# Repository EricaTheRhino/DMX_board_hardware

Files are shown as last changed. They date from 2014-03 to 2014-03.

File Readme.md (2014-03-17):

Hardware designs for Erica led controller
=========================================

Designs where made in eagle 6.4

Jumper options
--------------

SJ1/SJ2 used for DMX passthough if not populating second rs485 converter (U3)
SJ3 used for linking logic and led power systems together for use with a single power supply
SJ4 links return serial from TLC5940 to avr if wanted

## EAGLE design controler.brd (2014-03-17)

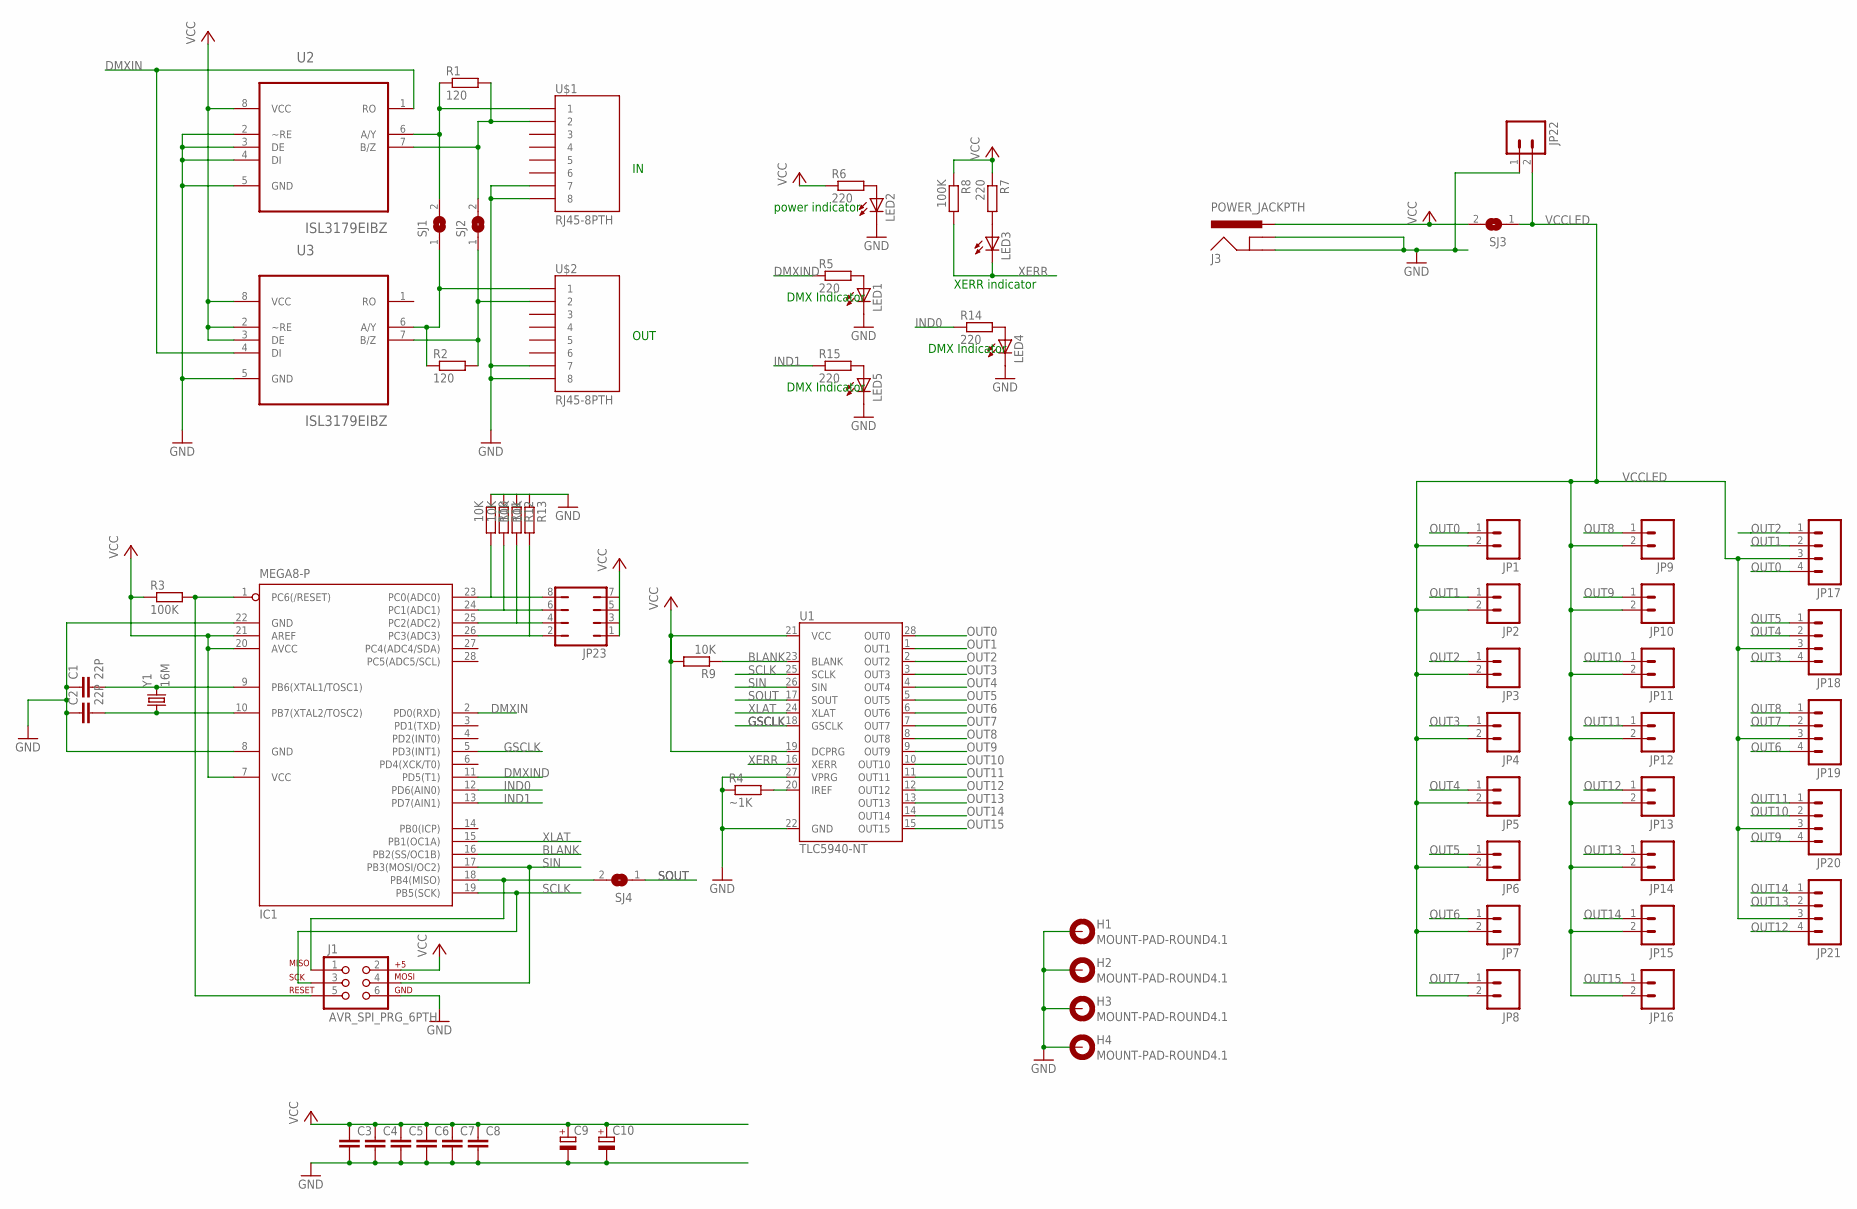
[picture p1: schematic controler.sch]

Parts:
C1, C2: 22P; C0603
C3, C4, C5, C6, C7, C8: C-EUC0603; C0603
C9: CPOL-EUE2.5-6; E2,5-6
C10: CPOL-EUE3.5-10; E3,5-10
H1, H2, H3, H4: MOUNT-PAD-ROUND4.1; 4,1-PAD
IC1: MEGA8-P; DIL28-3
J1: AVR_SPI_PRG_6PTH; 2X3
J3: POWER_JACKPTH; POWER_JACK_PTH
JP1, JP2, JP3, JP4, JP5, JP6, JP7, JP8, JP9, JP10, JP11, JP12, JP13, JP14, JP15, JP16: M02POLAR; MOLEX-1X2
JP17, JP18, JP19, JP20, JP21: M04POLAR; MOLEX-1X4
JP22: M023.5MM; SCREWTERMINAL-3.5MM-2
JP23: JP4Q
LED1, LED2, LED3, LED4, LED5: LEDCHIPLED_0603; CHIPLED_0603
R1, R2: 120; R0603
R3, R8: 100K; R0603
R4: ~1K; R0603
R5, R6, R7, R14, R15: 220; R0603
R9, R10, R11, R12, R13: 10K; R0603
SJ1, SJ2, SJ4: SJ
SJ3: SJW
U1: TLC5940-NT; DIL28-3
U2, U3: ISL3179EIBZ; SOIC127P600X175-8N
U$1, U$2: RJ45-8PTH; RJ45-8
Y1: 16M; HC49US

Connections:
BLANK: IC1.16 (PB2(SS/OC1B)), R9.1, U1.23 (BLANK)
DMXIN: IC1.2 (PD0(RXD)), U2.1 (RO), U3.4 (DI)
DMXIND: IC1.11 (PD5(T1)), R5.1
GND: C1.1, C2.1, C3.2, C4.2, C5.2, C6.2, C7.2, C8.2, C9.-, C10.-, H1.B4,1, H2.B4,1, H3.B4,1, H4.B4,1, IC1.8 (GND), IC1.22 (GND), J1.6, J3.GND, J3.GNDBREAK, JP22.1, LED1.C, LED2.C, LED4.C, LED5.C, R4.1, R10.1, R11.1, R12.1, R13.1, U1.22 (GND), U1.27 (VPRG), U2.2 (~RE), U2.3 (DE), U2.4 (DI), U2.5 (GND), U3.5 (GND), U$1.7, U$1.8, U$2.7, U$2.8
GSCLK: IC1.5 (PD3(INT1)), U1.18 (GSCLK)
IND0: IC1.12 (PD6(AIN0)), R14.1
IND1: IC1.13 (PD7(AIN1)), R15.1
unnamed: R1.1, SJ1.2, U2.6 (A/Y), U$1.1
unnamed: R1.2, SJ2.2, U2.7 (B/Z), U$1.2
unnamed: R2.1, SJ1.1, U3.6 (A/Y), U$2.1
unnamed: R2.2, SJ2.1, U3.7 (B/Z), U$2.2
unnamed: C1.2, IC1.9 (PB6(XTAL1/TOSC1)), Y1.2
unnamed: C2.2, IC1.10 (PB7(XTAL2/TOSC2)), Y1.1
unnamed: IC1.23 (PC0(ADC0)), JP23.8, R10.2
unnamed: IC1.24 (PC1(ADC1)), JP23.6, R11.2
unnamed: IC1.1 (PC6(/RESET)), J1.5, R3.2
unnamed: IC1.25 (PC2(ADC2)), JP23.4, R12.2
unnamed: IC1.18 (PB4(MISO)), J1.1, SJ4.2
unnamed: IC1.26 (PC3(ADC3)), JP23.2, R13.2
unnamed: LED5.A, R15.2
unnamed: R4.2, U1.20 (IREF)
unnamed: LED3.A, R7.2
unnamed: LED1.A, R5.2
unnamed: LED4.A, R14.2
unnamed: LED2.A, R6.2
OUT0: JP1.1, JP17.4, U1.28 (OUT0)
OUT1: JP2.1, JP17.2, U1.1 (OUT1)
OUT2: JP3.1, JP17.1, U1.2 (OUT2)
OUT3: JP4.1, JP18.4, U1.3 (OUT3)
OUT4: JP5.1, JP18.2, U1.4 (OUT4)
OUT5: JP6.1, JP18.1, U1.5 (OUT5)
OUT6: JP7.1, JP19.4, U1.6 (OUT6)
OUT7: JP8.1, JP19.2, U1.7 (OUT7)
OUT8: JP9.1, JP19.1, U1.8 (OUT8)
OUT9: JP10.1, JP20.4, U1.9 (OUT9)
OUT10: JP11.1, JP20.2, U1.10 (OUT10)
OUT11: JP12.1, JP20.1, U1.11 (OUT11)
OUT12: JP13.1, JP21.4, U1.12 (OUT12)
OUT13: JP14.1, JP21.2, U1.13 (OUT13)
OUT14: JP15.1, JP21.1, U1.14 (OUT14)
OUT15: JP16.1, U1.15 (OUT15)
SCLK: IC1.19 (PB5(SCK)), J1.3, U1.25 (SCLK)
SIN: IC1.17 (PB3(MOSI/OC2)), J1.4, U1.26 (SIN)
SOUT: SJ4.1, U1.17 (SOUT)
VCC: C3.1, C4.1, C5.1, C6.1, C7.1, C8.1, C9.+, C10.+, IC1.7 (VCC), IC1.20 (AVCC), IC1.21 (AREF), J1.2, J3.PWR, JP23.1, JP23.3, JP23.5, JP23.7, R3.1, R6.1, R7.1, R8.1, R9.2, SJ3.2, U1.19 (DCPRG), U1.21 (VCC), U2.8 (VCC), U3.2 (~RE), U3.3 (DE), U3.8 (VCC)
VCCLED: JP1.2, JP2.2, JP3.2, JP4.2, JP5.2, JP6.2, JP7.2, JP8.2, JP9.2, JP10.2, JP11.2, JP12.2, JP13.2, JP14.2, JP15.2, JP16.2, JP17.3, JP18.3, JP19.3, JP20.3, JP21.3, JP22.2, SJ3.1
XERR: LED3.C, R8.2, U1.16 (XERR)
XLAT: IC1.15 (PB1(OC1A)), U1.24 (XLAT)

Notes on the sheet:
OUT
DMX Indicator
power indicator
XERR indicator

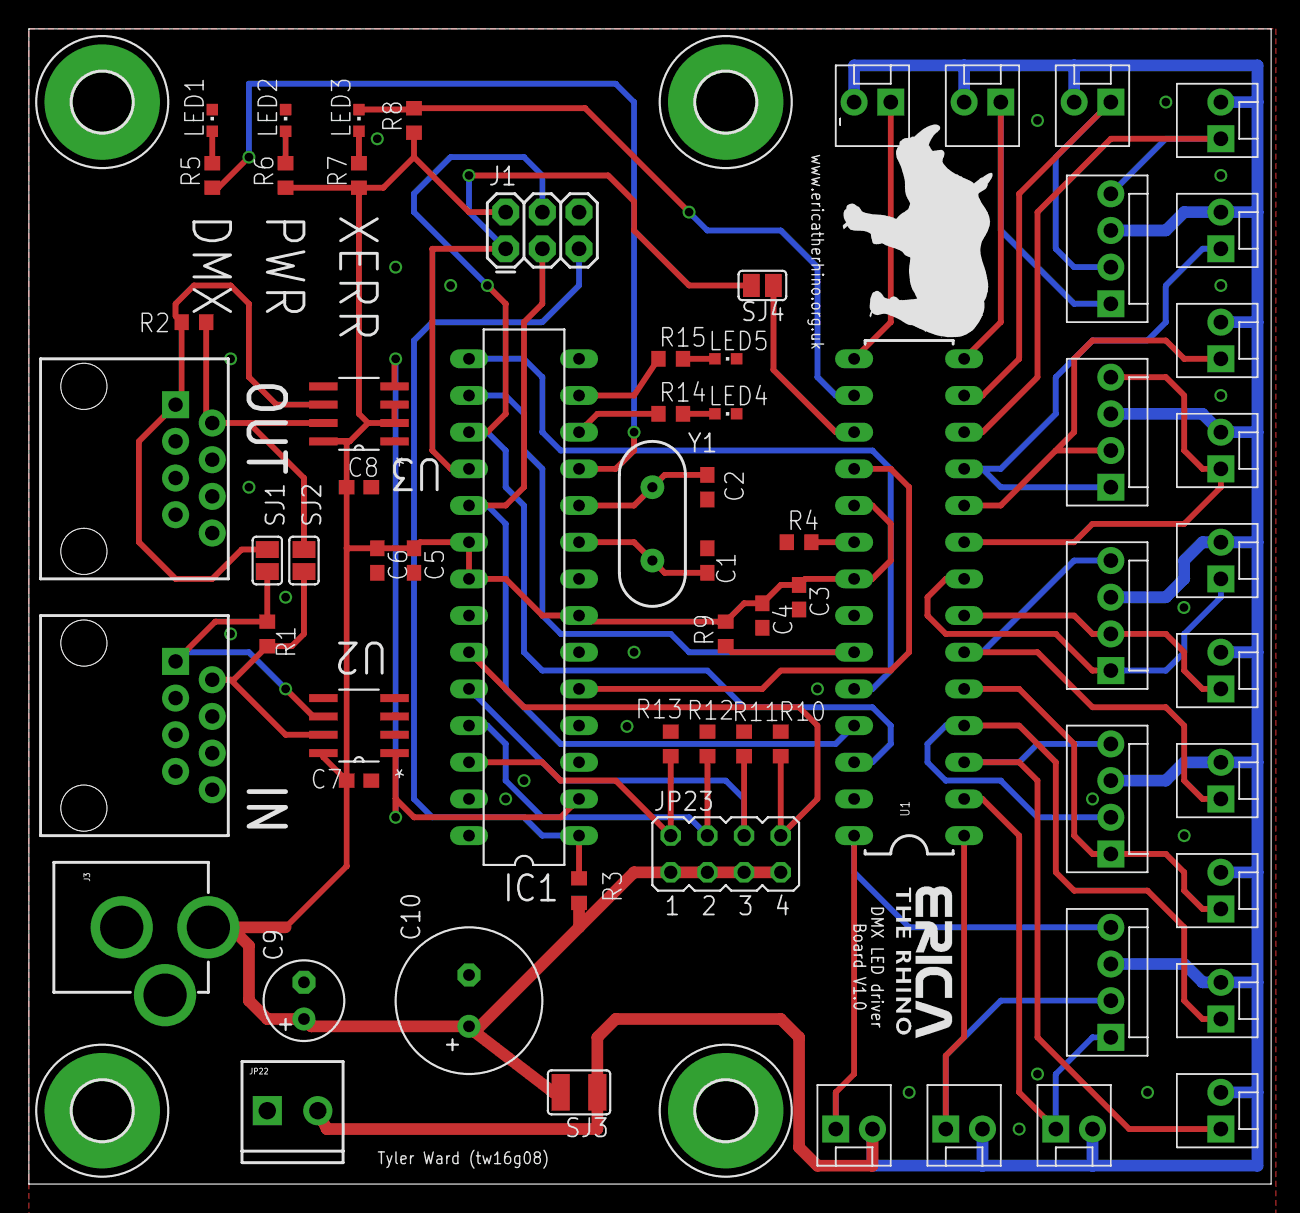
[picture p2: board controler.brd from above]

Board: 2 copper layers, 86.0 x 80.0 mm, 70 parts (0 on the bottom side), 48 nets.

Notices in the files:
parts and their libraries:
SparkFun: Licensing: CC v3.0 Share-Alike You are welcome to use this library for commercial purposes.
